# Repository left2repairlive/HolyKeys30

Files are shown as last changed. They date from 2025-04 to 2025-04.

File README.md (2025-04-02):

## Concept
I wanted a one-handed keyboard for gaming on the go, but the offerings on the market seemed cheap, quiet pricy and way to RGB and aggressive looking.
I decided to give it a try and started a wish-list:

1. wired (for now)
2. no RGB
3. no extras like a screen or knobs (for now)
4. no layering (broke that rule)

After getting started I decided to design the PCB 100% reversible, so I could populate it from either side and use the same PCB for a right or left hand keyboard if I ever wanted to extend this project to an actual typing keyboard.

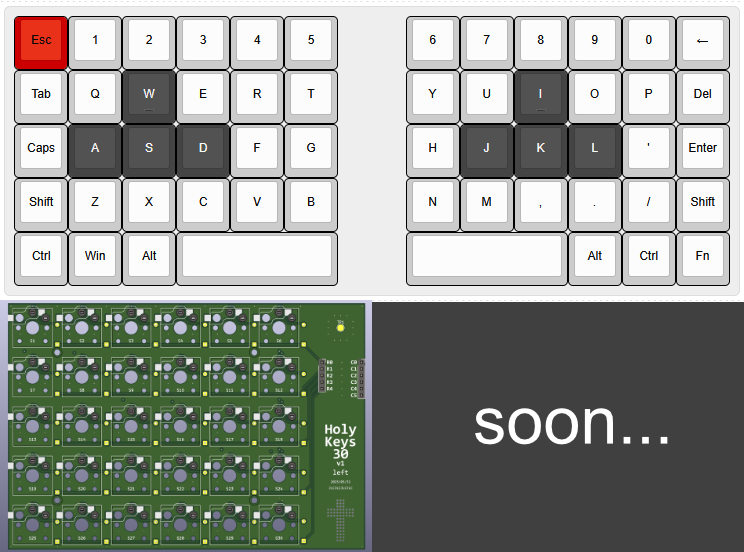
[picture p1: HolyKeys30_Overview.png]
Overview of HolyKeys design process


## Layout
I used Keyboard Layout Editor and came up with [this design](https://keyboard-layout-editor.com/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'&=Enter%3B&@=Shift&=Z&=X&=C&=V&=B&_x:1.25%3B&=N&=M&=,&=.&=%2F%2F&=Shift%3B&@=Ctrl&=Win&=Alt&_w:3%3B&=&_x:1.25&w:3%3B&=&=Alt&=Ctrl&=Fn) for both sides.
The 3u spacebar will still have all three units populated with hot swap sockets in case I want to actually use all 30 keys of the 6x5 grid.

## Switches
I defininetily wanted low-profile switches, finally deciding on Kalih Choc V2. I ordered a bunch of different switches to test out, but after playing around I landed on basic linear Reds. I will give tactile switches a try in the future.

## MCU-Selection
The Arduino Pro Micro seemed like the easiest and most popular choice, but I also ordered some others to play around with. The nRF-series seems very promosing in the future.
I designed the PCB to only have pin-sockets for the actual rows and columns I need, so I won't settle for on specific MCU right away, but can swap them out easily.

## Firmware
For the sake of fun I decided to write the firmware myself as a challenge for learning some more micro-controller programming.

## KiCAD libraries
* [kiswitch library](https://github.com/kiswitch/kiswitch)
* [ScottoKeebs library](https://github.com/joe-scotto/scottokeebs/tree/main/Extras/ScottoKicad)

*As said above I may have misused the relative paths for these libraries, so it needs fixing*

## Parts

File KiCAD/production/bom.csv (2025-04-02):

Designator | Footprint | Quantity | Value | LCSC Part #
D1, D10, D11, D12, D13, D14, D15, D16, D17, D18, D19, D2, D20, D21, D22, D23, D24, D25, D26, D27, D28, D29, D3, D30, D4, D5, D6, D7, D8, D9 | Diode_DO-35 | 30 | Diode
H1, H2, H3, H4 | MountingHole_2.2mm_M2_DIN965 | 4 | Mounting_Hole
J1 | PinSocket_1x05_P2.54mm_Vertical | 1 | Rows 1x5
J2 | PinSocket_1x06_P2.54mm_Vertical | 1 | Col 1x6
S1, S10, S11, S12, S13, S14, S15, S16, S17, S18, S19, S2, S20, S21, S22, S23, S24, S25, S26, S27, S28, S29, S3, S30, S4, S5, S6, S7, S8, S9 | SW_Hotswap_Kailh_Choc_V1V2_Reversible | 30 | Keyswitch
TP1, TP2 | TestPoint_Pad_D2.5mm | 2 | GND

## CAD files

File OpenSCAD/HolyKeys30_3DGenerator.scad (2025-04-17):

use <L2R_Keycap.scad>;


$fn = 8;


keyUnit = 19.05;

keyGrid = // [x, y, width, depth] in units
[
    [0,0,1,1], [1,0,1,1], [2,0,1,1], [4,0,3,1], 
    [0,1,1,1], [1,1,1,1], [2,1,1,1], [3,1,1,1], [4,1,1,1], [5,1,1,1],
    [0,2,1,1], [1,2,1,1], [2,2,1,1], [3,2,1,1], [4,2,1,1], [5,2,1,1],
    [0,3,1,1], [1,3,1,1], [2,3,1,1], [3,3,1,1], [4,3,1,1], [5,3,1,1],
    [0,4,1,1], [1,4,1,1], [2,4,1,1], [3,4,1,1], [4,4,1,1], [5,4,1,1],
];

rotate([180, 0, 0])
    for(key = keyGrid)
        translate([keyUnit * key[0], keyUnit * key[1], 0]) 
            keycap(size = [key[2], key[3]]);
        

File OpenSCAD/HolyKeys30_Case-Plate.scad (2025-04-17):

include<BOSL2/std.scad>

$fn = 64;


keyUnit = 19.05;
angle = 2;

pcbMargin = keyUnit / 32;
pcbClearance = keyUnit / 7;

wallStrength = keyUnit / 8;
wallHeight = keyUnit / 2;
bottomStrength = keyUnit / 8;

chocStabilizerBiggerRectDimensions = [6.30, 6.60] * 1.02;
chocStabilizerSmallerRectDimensions = [3.20, 3.60] * 1.02;

plateHoleDimensions = [13.95, 13.95];


extraMountingHolesOffset = (115.35 + keyUnit) / keyUnit;

mountingHolesGrid =
[
    [1, 1, 0],
    [5, 1, 0],
    [1, 4, 0],
    [5, 4, 0],
    [extraMountingHolesOffset, 1, 0],
    [extraMountingHolesOffset, 4, 0],
] * keyUnit;


threadedInsertDimensions = [3.2, 5, 2.5];

standoffHoleDiameter = threadedInsertDimensions[0];
standoffHoleHeight = threadedInsertDimensions[1];
standoffDiameter = standoffHoleDiameter * 2;

pcbDimensions = [7.25 * keyUnit, 5 * keyUnit, 1.6];
pcbTranslation = [wallStrength + pcbMargin, wallStrength + pcbMargin, bottomStrength + pcbClearance];

hotswapSocketNeededClearance = 1.8;
hotswapSocketOffset = [2.52, 4.9];
hotswapSocketSupportDimensions = [1.8, pcbClearance - 1.8];

outerDimensions = [pcbDimensions[0] + (wallStrength + pcbMargin) * 2, pcbDimensions[1] + (wallStrength + pcbMargin) * 2, bottomStrength + wallHeight];

innerCutoutDimensions = pcbDimensions + [pcbMargin * 2, pcbMargin * 2, wallHeight * 2];
innerCutoutTranslation = [wallStrength, wallStrength, bottomStrength];

wedgeAnle = 180 - 90 - angle;
wedgeHeight = outerDimensions[1] / sin(wedgeAnle) * sin(angle);

plateStrength = 1.65 * 0.76;
plateClearance = 0.8;

plateDimensions = [6 * keyUnit, 5 * keyUnit, plateStrength];
plateTranslation = pcbTranslation + [0, 0, plateClearance + pcbDimensions[2]];


keyGrid = // [x, y, width, height] in units
[
    [0,0,1,1], [1,0,1,1], [2,0,1,1], [4,0,1,1], 
    [0,1,1,1], [1,1,1,1], [2,1,1,1], [3,1,1,1], [4,1,1,1], [5,1,1,1],
    [0,2,1,1], [1,2,1,1], [2,2,1,1], [3,2,1,1], [4,2,1,1], [5,2,1,1],
    [0,3,1,1], [1,3,1,1], [2,3,1,1], [3,3,1,1], [4,3,1,1], [5,3,1,1],
    [0,4,1,1], [1,4,1,1], [2,4,1,1], [3,4,1,1], [4,4,1,1], [5,4,1,1],
];

stabilizerGrid =  // [x, y, width, height] in units
[
    [3, 0],
    [5, 0]
];


case();

*color("red", 0.5)
        plate();

*color("darkgreen", 0.3)
    pcbModel();



module case()
{
    difference()
    {
        union()
        {
            difference()
            {
                // outer shell
                cube(outerDimensions);

                // inner cutout
                translate(innerCutoutTranslation)
                    cube(innerCutoutDimensions);
                

            }

            // case wedge
            translate(v_mul(outerDimensions, [1,1,0]))
                rotate([0, 0, 180])
                    mirror([0, 0, 1])
                        wedge([outerDimensions[0], outerDimensions[1], wedgeHeight]);

            // standoff
            for(translation = mountingHolesGrid)
                translate(translation + v_mul(pcbTranslation, [1,1,0]))
                    cylinder(d = standoffDiameter, h = bottomStrength + pcbClearance);       
        }

        // standoff cutout
        for(translation = mountingHolesGrid)
            translate(translation + pcbTranslation + [0, 0, -standoffHoleHeight])
                cylinder(d = standoffHoleDiameter, h = outerDimensions[2]);
            
    }

    // hotswap socker supports
    translate(pcbTranslation + [keyUnit / 2, keyUnit / 2, -pcbClearance])
        for(key = keyGrid)
            translate(key * keyUnit + hotswapSocketOffset)
                cylinder(d = hotswapSocketSupportDimensions[0], hotswapSocketSupportDimensions[1]);
}


module plate()
{
    translate(plateTranslation)
        difference()
        {   
            union()
            {
                // plate
                cube(plateDimensions);
            
                // pcb clearance standoffs
                for(translation = mountingHolesGrid)
                    translate(translation)
                        translate([0, 0, -plateClearance])
                            cylinder(d = threadedInsertDimensions[2] * 2, h = plateClearance);
            }

            // key cutouts
            translate([keyUnit, keyUnit] / 2)
                for(key = keyGrid)
                    translate([key[0] * keyUnit, key[1] * keyUnit, plateStrength / 2])
                        cube([key[2] * plateHoleDimensions[0], key[3] * plateHoleDimensions[0], plateStrength * 2], center = true);
                        
            // stabilizer cutouts
            translate([keyUnit, keyUnit] / 2)
                for(stabilizer = stabilizerGrid)
                    translate([stabilizer[0] * keyUnit, stabilizer[1] * keyUnit])
                        linear_extrude(plateStrength)
                            chocStabilizerCutout();
                       

            // standoff cutout
            for(translation = mountingHolesGrid)
                translate(translation)
                    translate([0, 0, -plateClearance])
                        cylinder(d = threadedInsertDimensions[2], h = outerDimensions[2]);
        }
}



module chocStabilizerCutout()
{
    square([chocStabilizerBiggerRectDimensions[0], chocStabilizerBiggerRectDimensions[1]], center = true);
    
    translate([0, (chocStabilizerBiggerRectDimensions[1] + chocStabilizerSmallerRectDimensions[1]) / 2])
        square([chocStabilizerSmallerRectDimensions[0], chocStabilizerSmallerRectDimensions[1]], center = true);
}



module pcbModel()
{
        translate([wallStrength + pcbMargin, pcbDimensions[1] + wallStrength + pcbMargin, bottomStrength + pcbClearance])
            import("export/HolyKeys30.stl");
}

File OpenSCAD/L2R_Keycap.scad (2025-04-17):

include<BOSL2/std.scad>
include <BOSL2/rounding.scad>

defaultHorizontalUnit = 19.05;
defaultVerticalUnit = defaultHorizontalUnit;

defaultKeycapScale = 0.95;
defaultBotToTopScale = 0.95;

defaultKeyHeight  = 5;
defaultWallThickness = 1.2;
defaultCornerRadius = 2;
defaultTopEdgeRadius = 1;

allowedStems = ["MX", "ChocV1"];

defaultTextStyle =
[
    0.2, // depth of text embossing
    8, // font size
    "Consolas:style=Bold", // font family
    1, // text spacing
    [0, 0] // offset
];




module keycap(
    size = [1, 1],
    stabilizerStemDistance = 0,
    stem = "MX",
    stabilizerStem = "MX",
    horizontalUnit = defaultHorizontalUnit,
    verticalUnit = defaultVerticalUnit,
    keycapScale = defaultKeycapScale,
    botToTopScale = defaultBotToTopScale,
    keyHeight = defaultKeyHeight,
    wallThickness = defaultWallThickness,
    cornerRadius = defaultCornerRadius,
    topEdgeRadius = defaultTopEdgeRadius,
    text = "",
    textStyle = defaultTextStyle
)
{
    width = size[0];
    depth = size[1];

    keycapSizeAbsoluteReduction = verticalUnit * (1 - keycapScale);
    keycapBotToTopAbsoluteReduction = keycapSizeAbsoluteReduction * botToTopScale;

    switchLowerFootprint = [width * horizontalUnit - keycapSizeAbsoluteReduction, depth * verticalUnit - keycapSizeAbsoluteReduction];
    switchUpperFootprint = switchLowerFootprint - [keycapBotToTopAbsoluteReduction, keycapBotToTopAbsoluteReduction];

    innerLowerFootprint = switchLowerFootprint - [wallThickness * 2, wallThickness * 2];
    innerUpperFootprint = switchUpperFootprint - [wallThickness * 2, wallThickness * 2];

    innerHeight = keyHeight - wallThickness;
    
    innerEdgeRadius = cornerRadius - wallThickness;

    stemHeight = innerHeight;


    difference()
    {
        //prismoid(size1 = switchLowerFootprint, size2 = switchUpperFootprint, rounding = edgeRadius, h = keyHeight);

        up(keyHeight / 2)
            rounded_prism(bottom = rect(switchLowerFootprint, rounding = cornerRadius), top = rect(switchUpperFootprint, rounding = cornerRadius), height = keyHeight, joint_top = topEdgeRadius, joint_bot = 0);

        prismoid(size1 = innerLowerFootprint, size2 = innerUpperFootprint, rounding = innerEdgeRadius, h = innerHeight);

        translate([textStyle[4][0], textStyle[4][1], keyHeight - textStyle[0]])
            linear_extrude(textStyle[0])
                text(text = text, valign = "center", halign = "center", size = textStyle[1], font = textStyle[2], spacing = textStyle[3]);
    }

    if(len(search([stem], allowedStems)) > 0)
    {
        if(stem == "MX")
        {
            mxStem();
        }
    }

    if(stabilizerStemDistance > 0)
    {
        if(len(search([stem], allowedStems)) > 0)
        {
            if(stem == "MX")
            {
                for(i = [-stabilizerStemDistance / 2, stabilizerStemDistance / 2])
                    translate([i, 0, 0])
                        mxStem();
            }
        }
    }
}



module mxStem(stemHeight = defaultKeyHeight - defaultWallThickness)
{
    // taken from: https://cdn.shopify.com/s/files/1/0657/6075/5954/files/SPEC-CPG135301D01_Kailh_Choc_V2_Low_Profile_Red_Switch.pdf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
    mxStemOuterDiamter = 5.5;
    mxStemCutoutDimensions = [4.1, 1.3, mxStemOuterDiamter] * 1.06;

    difference()
    {
        cylinder(d = mxStemOuterDiamter, h = stemHeight);

        for(i = [0, 1])
            translate([0, 0, mxStemCutoutDimensions[2] / 2])
                rotate([0, 0, 90 * i])
                    cube(mxStemCutoutDimensions, center = true);

    }

 
}

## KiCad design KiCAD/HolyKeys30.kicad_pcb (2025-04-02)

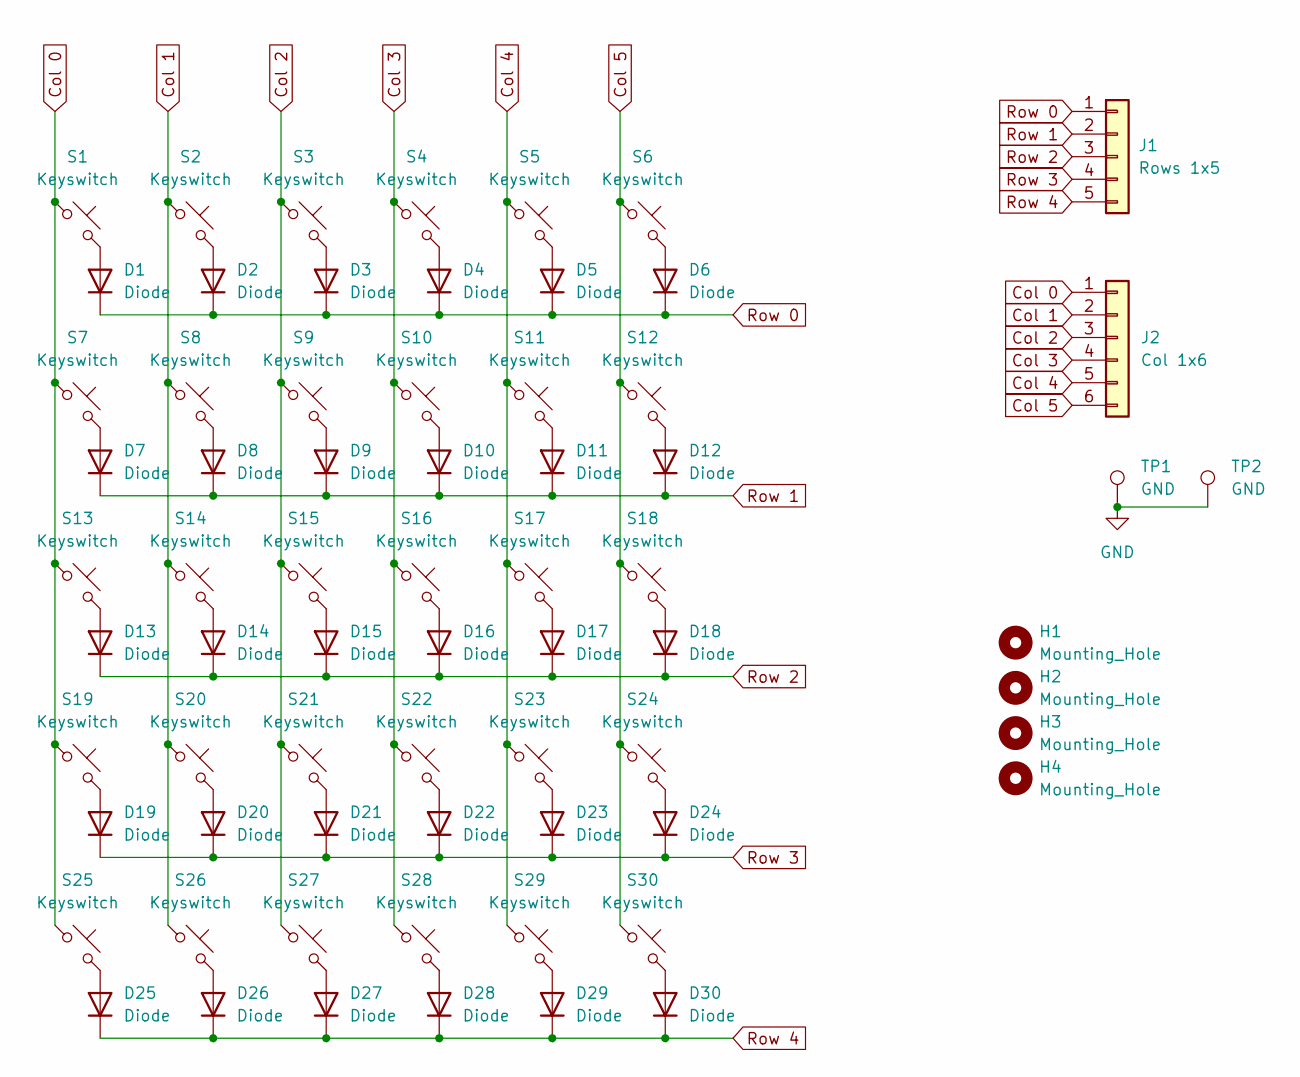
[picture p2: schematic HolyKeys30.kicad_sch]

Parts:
D1, D2, D3, D4, D5, D6, D7, D8, D9, D10, D11, D12, D13, D14, D15, D16, D17, D18, D19, D20, D21, D22, D23, D24, D25, D26, D27, D28, D29, D30: Diode; Diode_DO-35
H1, H2, H3, H4: Mounting_Hole; MountingHole_2.2mm_M2_DIN965
J1: Rows 1x5; PinSocket_1x05_P2.54mm_Vertical
J2: Col 1x6; PinSocket_1x06_P2.54mm_Vertical
S1, S2, S3, S4, S5, S6, S7, S8, S9, S10, S11, S12, S13, S14, S15, S16, S17, S18, S19, S20, S21, S22, S23, S24, S25, S26, S27, S28, S29, S30: Keyswitch; SW_Hotswap_Kailh_Choc_V1V2_Reversible
TP1, TP2: GND; TestPoint_Pad_D2.5mm

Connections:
Col 0: J2.1, S1.1, S7.1, S13.1, S19.1, S25.1
Col 1: J2.2, S2.1, S8.1, S14.1, S20.1, S26.1
Col 2: J2.3, S3.1, S9.1, S15.1, S21.1, S27.1
Col 3: J2.4, S4.1, S10.1, S16.1, S22.1, S28.1
Col 4: J2.5, S5.1, S11.1, S17.1, S23.1, S29.1
Col 5: J2.6, S6.1, S12.1, S18.1, S24.1, S30.1
GND: TP1.1, TP2.1
unnamed: D1.2 (A), S1.2
unnamed: D2.2 (A), S2.2
unnamed: D3.2 (A), S3.2
unnamed: D4.2 (A), S4.2
unnamed: D5.2 (A), S5.2
unnamed: D6.2 (A), S6.2
unnamed: D7.2 (A), S7.2
unnamed: D8.2 (A), S8.2
unnamed: D9.2 (A), S9.2
unnamed: D10.2 (A), S10.2
unnamed: D11.2 (A), S11.2
unnamed: D12.2 (A), S12.2
unnamed: D13.2 (A), S13.2
unnamed: D14.2 (A), S14.2
unnamed: D15.2 (A), S15.2
unnamed: D16.2 (A), S16.2
unnamed: D17.2 (A), S17.2
unnamed: D18.2 (A), S18.2
unnamed: D19.2 (A), S19.2
unnamed: D20.2 (A), S20.2
unnamed: D21.2 (A), S21.2
unnamed: D22.2 (A), S22.2
unnamed: D23.2 (A), S23.2
unnamed: D24.2 (A), S24.2
unnamed: D25.2 (A), S25.2
unnamed: D26.2 (A), S26.2
unnamed: D27.2 (A), S27.2
unnamed: D28.2 (A), S28.2
unnamed: D29.2 (A), S29.2
unnamed: D30.2 (A), S30.2
Row 0: D1.1 (K), D2.1 (K), D3.1 (K), D4.1 (K), D5.1 (K), D6.1 (K), J1.1
Row 1: D7.1 (K), D8.1 (K), D9.1 (K), D10.1 (K), D11.1 (K), D12.1 (K), J1.2
Row 2: D13.1 (K), D14.1 (K), D15.1 (K), D16.1 (K), D17.1 (K), D18.1 (K), J1.3
Row 3: D19.1 (K), D20.1 (K), D21.1 (K), D22.1 (K), D23.1 (K), D24.1 (K), J1.4
Row 4: D25.1 (K), D26.1 (K), D27.1 (K), D28.1 (K), D29.1 (K), D30.1 (K), J1.5

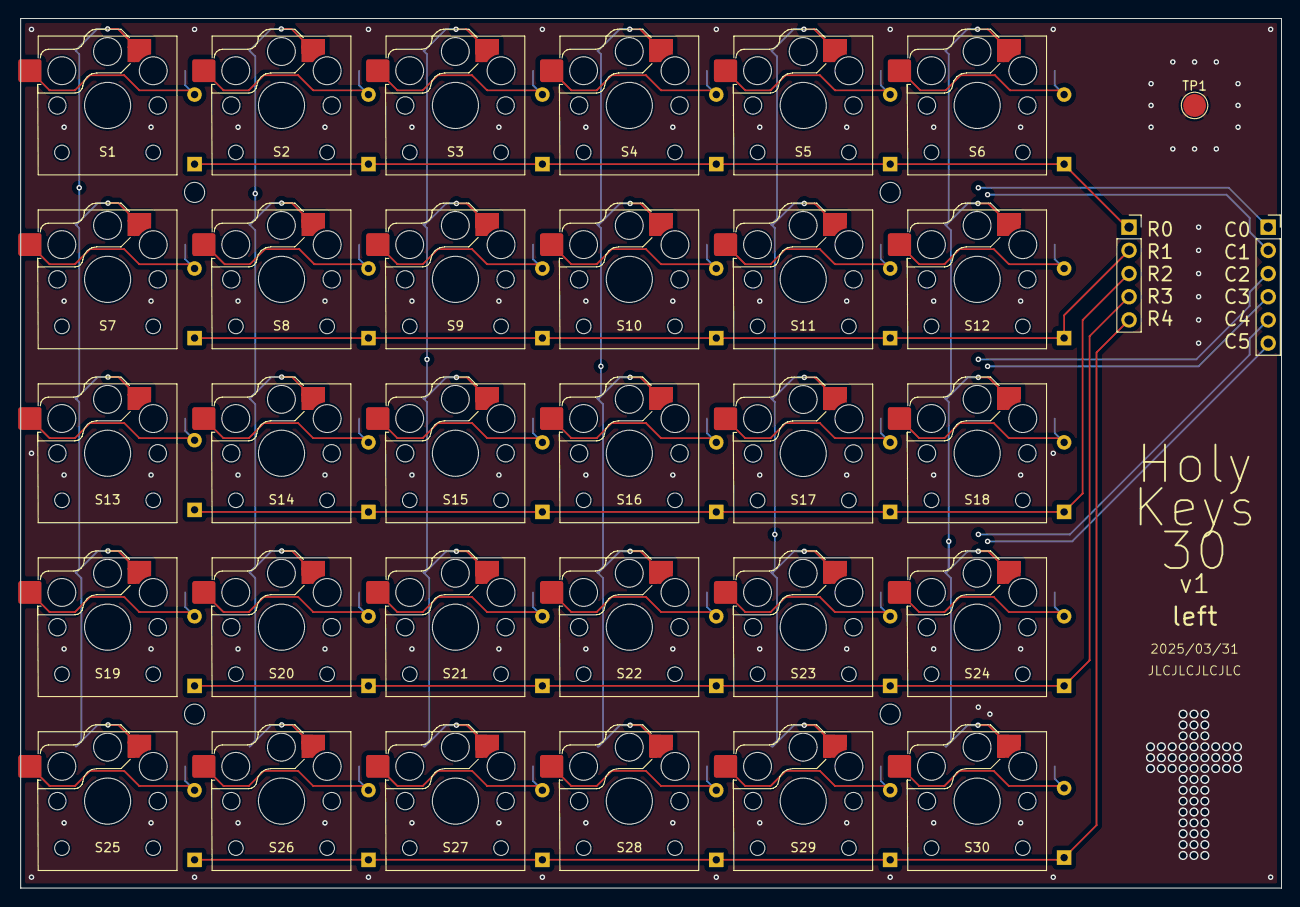
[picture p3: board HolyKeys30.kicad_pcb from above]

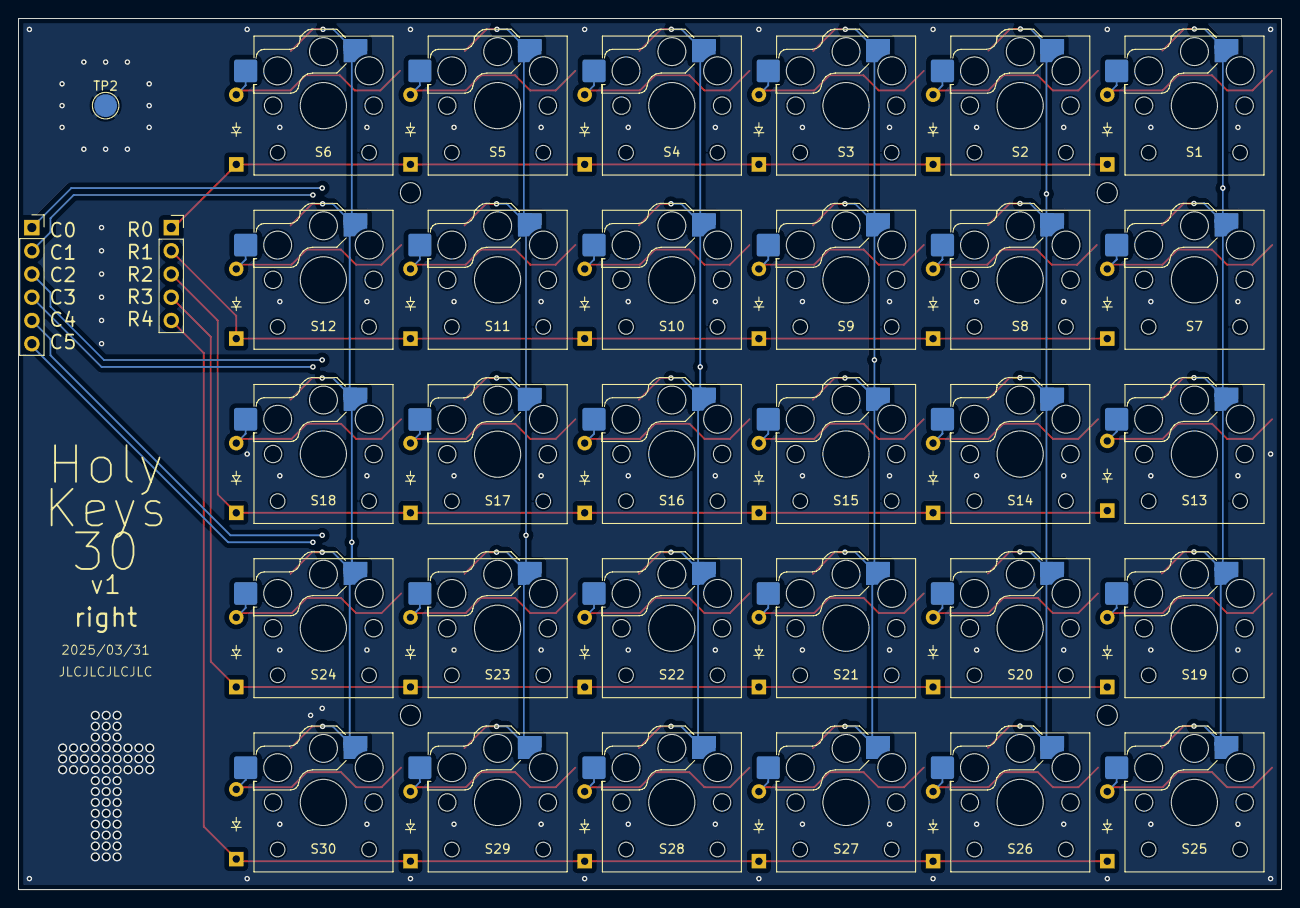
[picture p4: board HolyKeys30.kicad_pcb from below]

Board: 4 copper layers, 138.1 x 95.2 mm, 68 parts (31 on the bottom side), 42 nets.

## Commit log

2025-04-02 Designed parametric keycap and renamed files
    [HolyKeeb30_Switches.scad, HolyKeys30_Case-Plate.scad, HolyKeys30_Switches.scad]
2025-04-02 Updated plate to incorporate stabilizers
    [HolyKeys30_Case-Plate.scad]
2025-04-15 Adjusted custom keycaps for better sizing and fit
    [HolyKeys30_Switches.scad]
2025-04-15 Added angle variable and choc v2 stabilizers
    [HolyKeys30_Case-Plate.scad]
2025-04-15 Minor tweaks to dimensions
    [HolyKeys30_Case-Plate.scad]
2025-04-17 Started refactoring 3D design to make it more modular
    [HolyKeys30_3DGenerator.scad, HolyKeys30_Case-Plate.scad, HolyKeys30_Switches.scad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]
